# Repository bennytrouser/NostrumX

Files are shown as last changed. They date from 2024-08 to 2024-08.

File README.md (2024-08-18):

# NostrumX
A 32 key ergonomic split keyboard using Seeed Xiao BLE

This keyboard is a variation on my original [Nostrum](https://github.com/bennytrouser/nostrum) using a Seeeduino Xiao BLE with the battery mounted under the PCB within the case. Not designed to be used without the case.

The aim was to create a case based board while maintaining as much of the original shape and clean lines of the original nostrum pcb. 

- 3° Splay on pinky and ring columns
- Choc V1 switch compatible (hotswap or soldered). Hotswap recomennded as the switch plate is integrated into the case.
- Custom mildly tented case including switch sliders.
- MCU not socketed, SMD soldered only.
- Created with the [ergogen](https://github.com/ergogen/ergogen) and KiCad8. Case files created with Autodesk Fusion360.
- Firmware using ZMK, including the RGB Widget module from [Caksoylar](https://github.com/caksoylar/zmk-rgbled-widget)
- Inspiration from the [Hummingbird](https://github.com/PJE66/hummingbird) style [Berylline](https://github.com/jcmkk3/trochilidae#berylline) by [jcmkk3](https://github.com/jcmkk3)
- Mousebite breakaway tabs design are inspired by Sadekbaroudi's [bykeeb](https://github.com/sadekbaroudi/bykeeb)

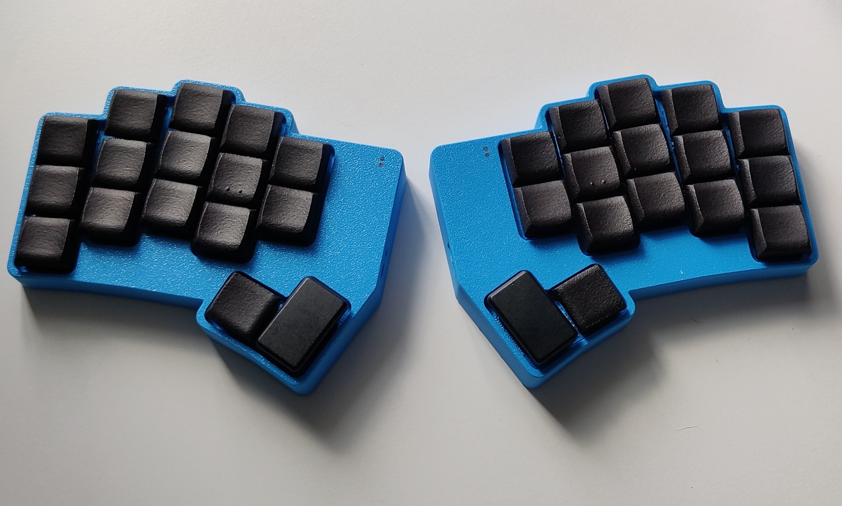
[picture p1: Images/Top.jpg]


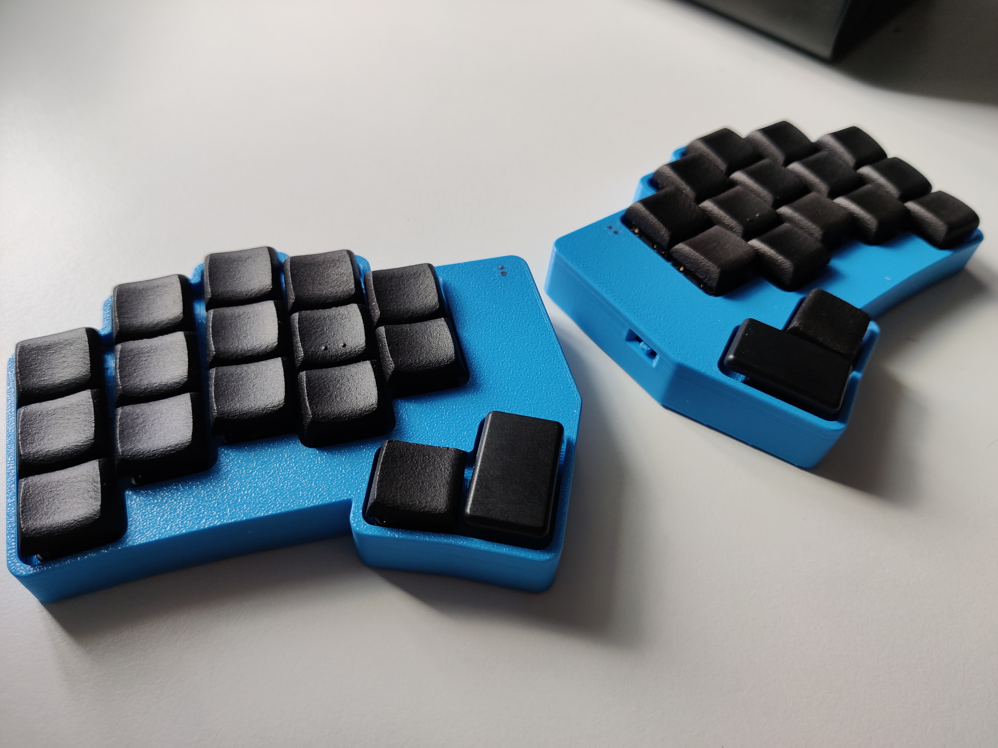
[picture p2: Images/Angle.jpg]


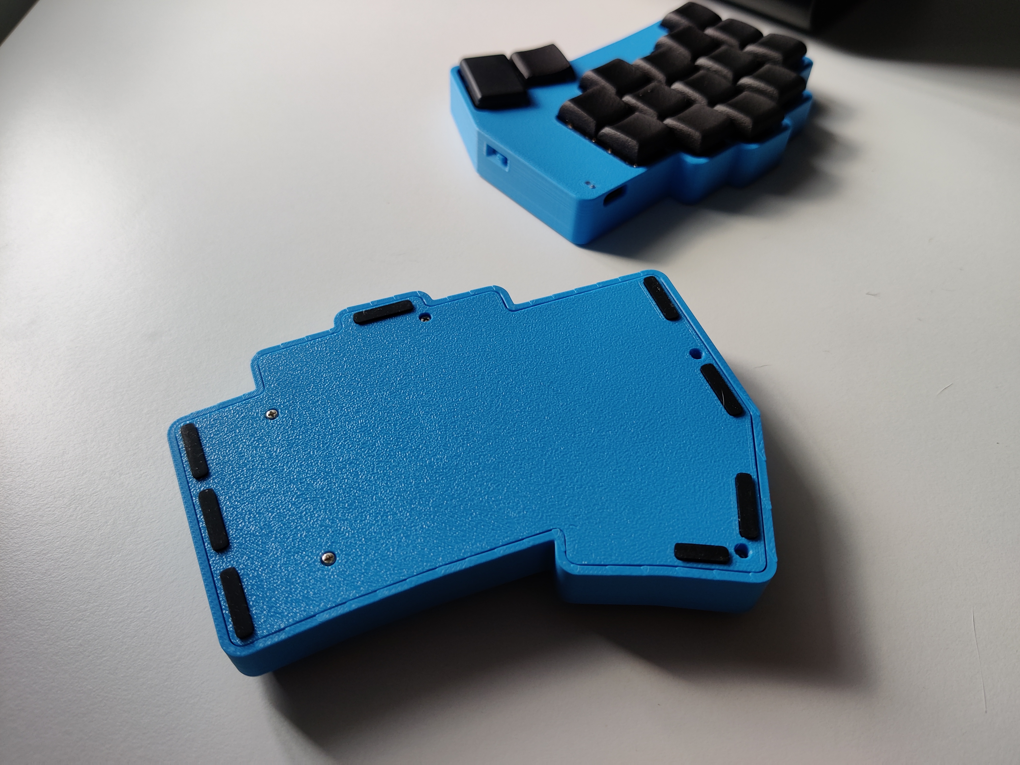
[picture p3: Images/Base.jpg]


## PCB
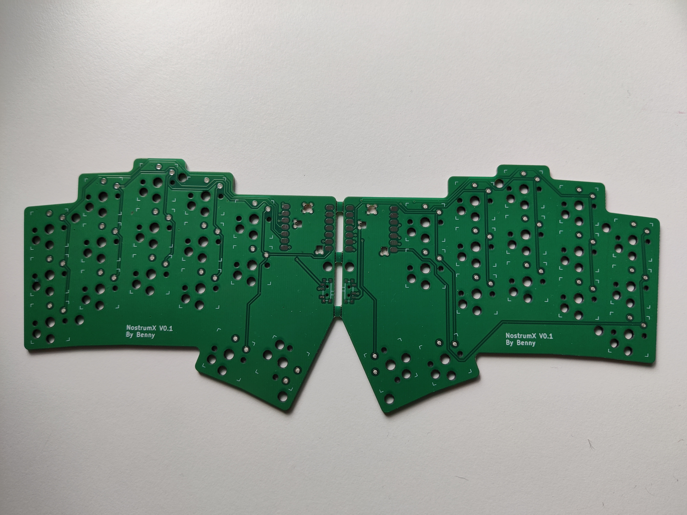
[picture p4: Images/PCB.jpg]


## Parts
The case is designed to be fastened from the underside using M1.5x6mm self tapping screws. Feet used are 10x3x1.5mm and 14x3x1.5mm. Left side has space to fit a lipo Battery 402030(180mah). Due to constraints, the right side will need a narrower battery if using hotswap. For my build, I used a 401322 (120mah) but a different size may fit. Example parts listed below. Source your switches and sockets and MCUs where available.

| Part  | Link |
| --- | --- |
| Battery 402030 | https://www.ebay.co.uk/itm/355875616696 |
| Battery 401322 | https://www.ebay.co.uk/itm/195234785175 |
| Self tapping Screws M1.5x6mm | https://www.aliexpress.com/item/1005005469153402.html |
| SMD diodes SOD-123 1N4148W T4 | https://www.aliexpress.com/item/32948518338.html |
| 1.5mm Fibreoptic cable (for led shinethrough) | https://www.aliexpress.com/item/1005005886250822.html |
| Reset button TL3342 | https://www.aliexpress.com/item/1005007506687094.html |
| Power switch PCM12 | https://www.aliexpress.com/item/32912838968.html |
| Feet | https://www.aliexpress.com/item/1005006691343859.html |

## Case files
Designed in Fusion360. 3d printed. Recommended to print the top case with face down for texured finish. There are two different bottoms, with or without a hole for a reset switch depending on if you want to use one.

The Switch bits need to be fitted before installing the pcb and are a tight fit. Also may require a bit of jiggling to get the slider to seat correctly on install.

The holes on the top of the case allow the charge led and the user led to shine through. I have used fibre optic cable in these holes but it is optional and a tight fit that may require slight enlargement with a screwdriver or small drillbit for the cable to slide in. Any larger in the file and it's a little loose.

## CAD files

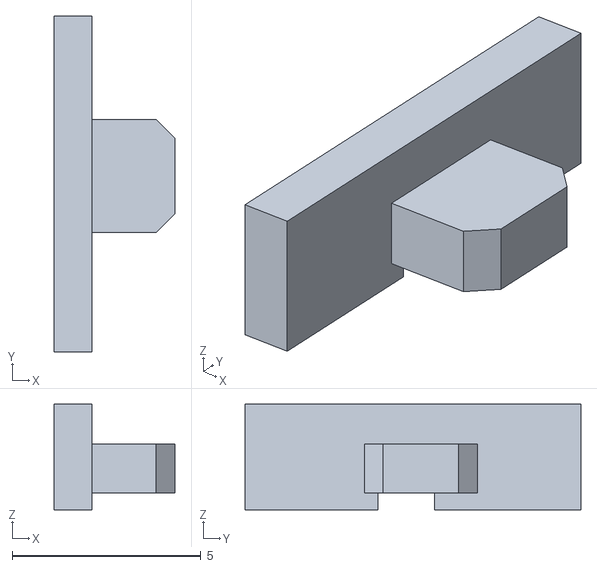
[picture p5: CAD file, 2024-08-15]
Case STLs/Switch bit Left.stl
3.20 x 8.90 x 2.80

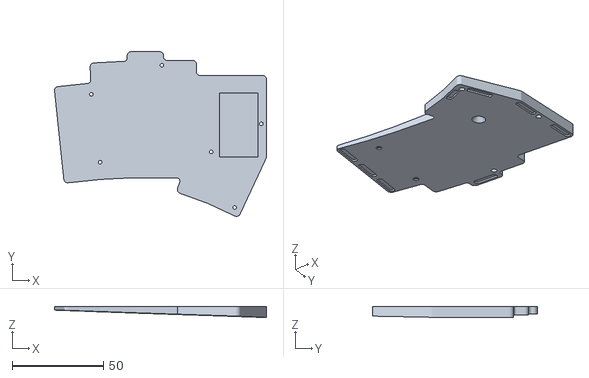
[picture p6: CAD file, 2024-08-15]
Case STLs/Left Bottom Case with reset.stl
115.9 x 90.1 x 6.12

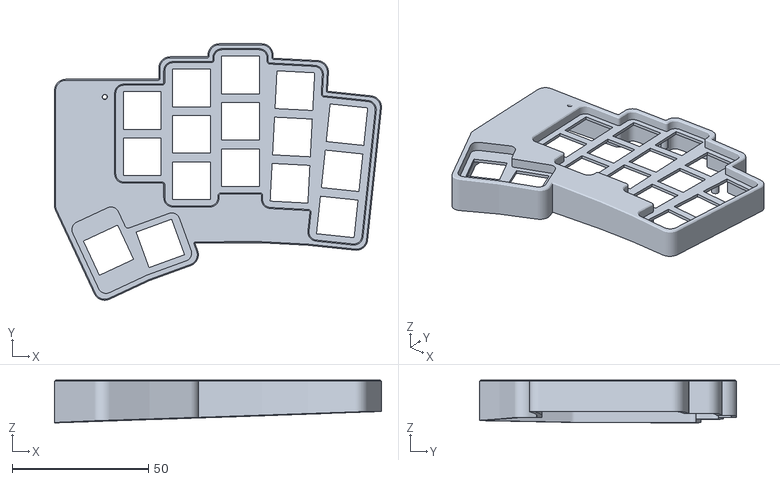
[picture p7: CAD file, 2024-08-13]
Case STLs/Right Top.stl
119.9 x 94.1 x 15.7

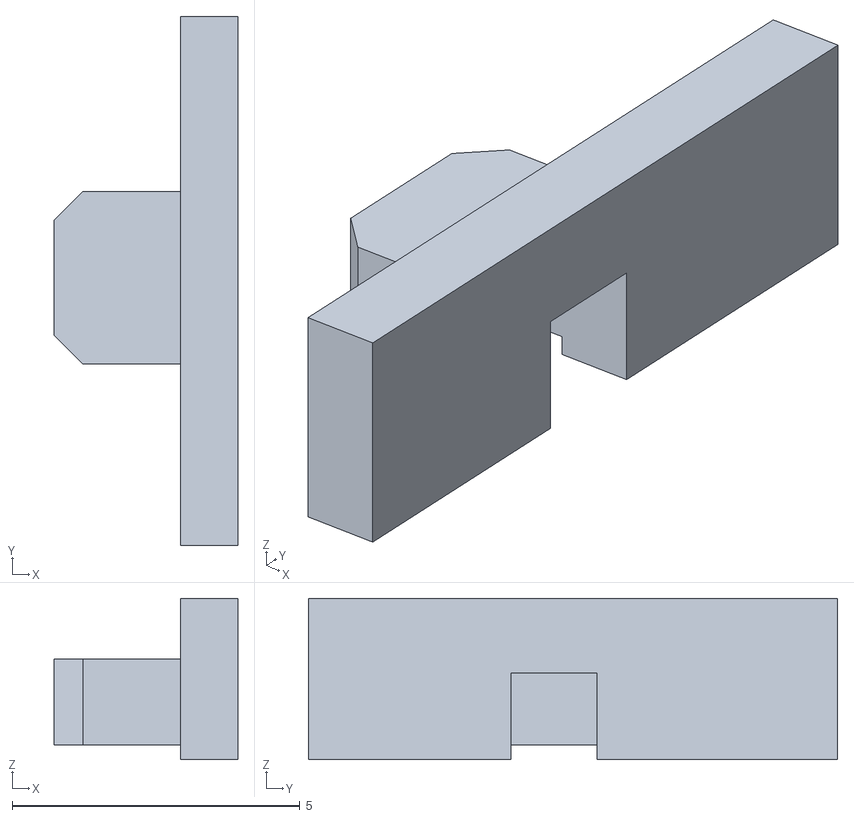
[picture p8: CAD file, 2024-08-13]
Case STLs/Switch bit Right.stl
3.20 x 9.20 x 2.80

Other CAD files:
Case STLs/Right Bottom Case with reset.stl
Case STLs/Right Bottom no reset hole.stl
Case STLs/Left Bottom no reset hole.stl
Case STLs/Left Top.stl

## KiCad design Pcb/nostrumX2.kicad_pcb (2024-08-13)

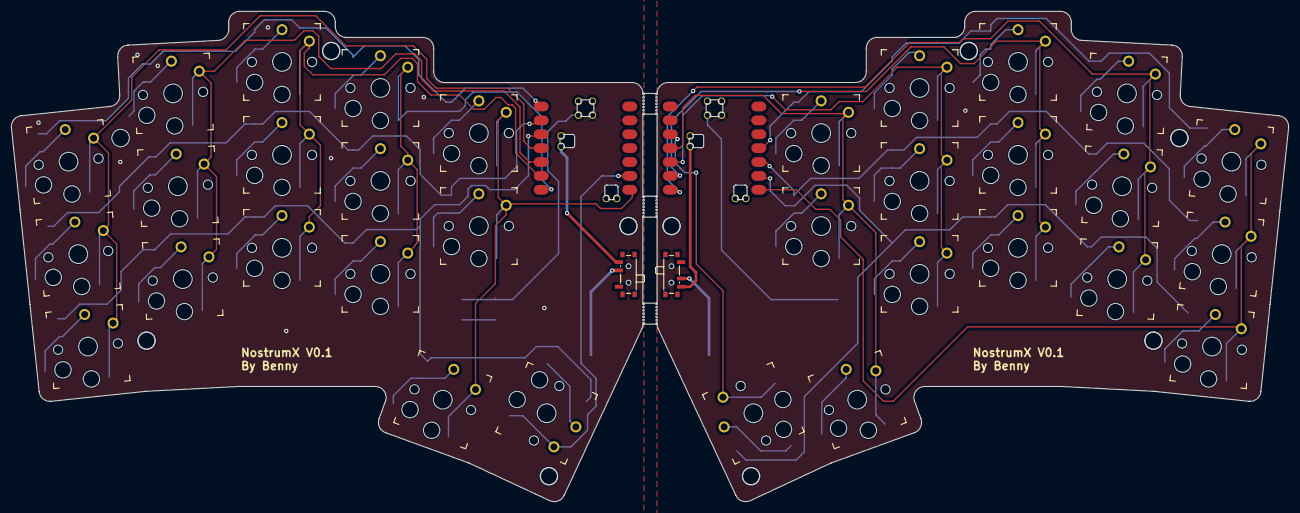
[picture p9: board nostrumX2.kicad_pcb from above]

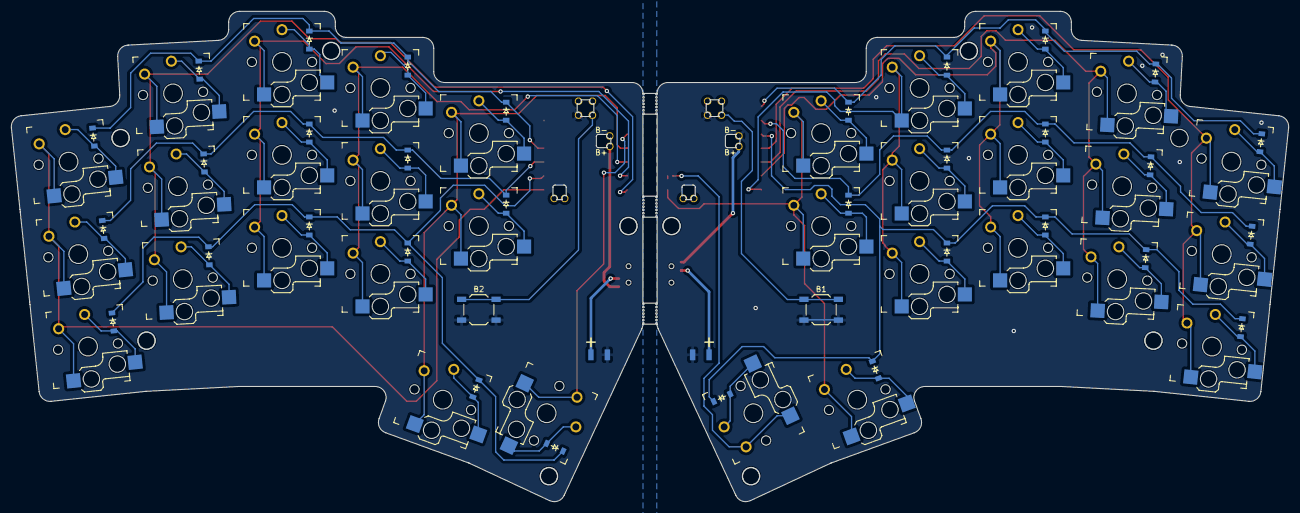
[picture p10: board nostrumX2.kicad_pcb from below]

Board: 2 copper layers, 233.6 x 89.7 mm, 79 parts (34 on the bottom side), 52 nets.

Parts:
B1, B2: SW_SPST_TL3342
D1, D2, D3, D4, D5, D6, D7, D8, D9, D10, D11, D12, D13, D14, D15, D16, D17, D18, D19, D20, D21, D22, D23, D24, D25, D26, D27, D28, D29, D30, D31, D32: ComboDiode
LH1, LH2, LH3: Breakaway Tabs; Breakaway_Tabs_Med
Mount: MountingHole_3.2mm_M3
PAD1, PAD2, PAD3, PAD4: SMDPad
RH1, RH2, RH3: Breakaway Tabs; Breakaway_Tabs_Med
S1, S2, S3, S4, S5, S6, S7, S8, S9, S10, S11, S12, S13, S14, S15, S16, S17, S18, S19, S20, S21, S22, S23, S24, S25, S26, S27, S28, S29, S30, S31, S32: PG1350
SW1, SW2: SW_SPDT_PCM12

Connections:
C0: S1.1, S2.1, S3.1
C1: S4.1, S5.1, S6.1
C2: S7.1, S8.1, S9.1
C3: S10.1, S11.1, S12.1
C4: S13.1, S14.1, S29.1
GND: B1.2, PAD2.1
MC0: S15.1, S16.1, S17.1
MC1: S18.1, S19.1, S20.1
MC2: S21.1, S22.1, S23.1
MC3: S24.1, S25.1, S26.1
MC4: S27.1, S28.1, S31.1
MGND: B2.2, PAD4.1
MR0: D19.1, D22.1, D25.1, D28.1, D30.1
MR1: D18.1, D21.1, D24.1, D27.1, D29.1
MR2: D17.1, D20.1, D23.1, D26.1, D31.1, D32.1
Mpos: PAD3.1, SW2.2
R0: D3.1, D6.1, D9.1, D12.1, D14.1
R1: D2.1, D5.1, D8.1, D11.1, D13.1
R2: D1.1, D4.1, D7.1, D10.1, D15.1, D16.1
index_bottom: D10.2, S10.2
index_home: D11.2, S11.2
index_top: D12.2, S12.2
inner_bottom: D13.2, S13.2
inner_home: D14.2, S14.2
left_home: D15.2, S29.2
middle_bottom: D7.2, S7.2
middle_home: D8.2, S8.2
middle_top: D9.2, S9.2
mirror_index_bottom: D26.2, S24.2
mirror_index_home: D27.2, S25.2
mirror_index_top: D28.2, S26.2
mirror_inner_bottom: D29.2, S27.2
mirror_inner_home: D30.2, S28.2
mirror_left_home: D31.2, S31.2
mirror_middle_bottom: D23.2, S21.2
mirror_middle_home: D24.2, S22.2
mirror_middle_top: D25.2, S23.2
mirror_pinky_bottom: D17.2, S15.2
mirror_pinky_home: D18.2, S16.2
mirror_pinky_top: D19.2, S17.2
mirror_right_home: D32.2, S32.2
mirror_ring_bottom: D20.2, S18.2
mirror_ring_home: D21.2, S19.2
mirror_ring_top: D22.2, S20.2
pinky_bottom: D1.2, S1.2
pinky_home: D2.2, S2.2
pinky_top: D3.2, S3.2
pos: PAD1.1, SW1.2
right_home: D16.2, S30.2
ring_bottom: D4.2, S4.2
ring_home: D5.2, S5.2
ring_top: D6.2, S6.2

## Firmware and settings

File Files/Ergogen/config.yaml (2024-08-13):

units:
  capx: 17.5   # Actual mbk size
  capy: 16.5   # Actual mbk size
  thumbcapx: 26.5 # Actual mbk 1.5u length
  kx: cx + 0.5    # Key spacing horizontal
  ky: cy + 0.5    # Key spacing vertical
  pinky_splay: 3  # Degrees of splay between pinky and ring columns
  pinky_adj: -10   # Adjustment to compensate for splay spacing
  ring_splay: 3
  ring_adj: -8
  middle_splay: 0
  middle_adj: 0
  thumb_offsetx: 0.25kx
  xiao_x: 17.5
  xiao_y: 21
  outx: 0.5capx +1  # Used for plate outlines
  outy: 0.5capy +1  # Used for plate outlines
  mirshift: 31

points:
  # Key Zones
  zones:
  zones.matrix:
    anchor:
      shift: [100,-100]
      rotate: ring_splay + pinky_splay
    mirror:
      ref: matrix_inner_home
      shift: mirshift
    key:
      width: capx
      height: capy
      spread: cx      
      padding: cy
    rows:
      bottom:
        row_net: R2
        mirror.row_net: MR2
        bind: [1, 1, 1, 1]
      home:
        row_net: R1
        mirror.row_net: MR1
        bind: [1, 1.5, 0, 1]
      top:
        row_net: R0
        mirror.row_net: MR0
        bind: [1, 2, 0, 1]
    columns:
      pinky:
        key:
          column_net: C0
          mirror.column_net: MC0
          rows:
            bottom:
              bind: [1, 1, 1, 1]
            home:
              bind: [1, 1.5, 0, 1]
            top:
              bind: [1, 2, 0, 1]
      ring:
        key:
          column_net: C1
          mirror.column_net: MC1
          stagger: 0.55U
          splay: -pinky_splay
          origin: [0, pinky_adj]
        rows:
          bottom:
            bind: [1,1.5,11.9,0]
          home:
            bind: [1,1.5,0,1]
          top.:
            ind: [1,2,1,1]
      middle:
        key:
          column_net: C2
          mirror.column_net: MC2
          stagger: 0.25U
          splay: -ring_splay
          origin: [0, ring_adj]
        rows:
          bottom:
            bind: [1,1,17.1,0]
          home:
            bind: [1,1,0,1]
          top:
            bind: [1,1,0,1]
      index:
        key:
          column_net: C3
          mirror.column_net: MC3
          stagger: -0.25U
        rows:
          bottom:
            bind: [1,1,12.341,1]
          home:
            bind: [1,1,0,1]
          top:
            bind: [1,1,0,1]
      inner:
        key:
          column_net: C4
          mirror.column_net: MC4
          stagger: 0.5ky
        rows:
          top.skip: true
          bottom:
            row_net: R1
            mirror.row_net: MR1
            bind: [1,2,22.590471307,1]
          home:
            row_net: R0
            mirror.row_net: MR0
            bind: [1,2,20,1]
  zones.thumb:
    anchor:
      ref: matrix_index_top
      shift: [0.6u,-57]
      rotate: -20
    mirror:
      ref: matrix_inner_home
      shift: mirshift
    key:
      width: capx
      height: capy
    rows:
      home:
        row_net: R2
        mirror.row_net: MR2
    columns:
      left.key:
        name: thumb_tucky
        bind: [0,3,1,1] # U,R,D,L
        column_net: C4
        mirror.column_net: MC4
      right.key:
        spread: kx+0.2
        stagger: 0.225kx
        rotate: -95
        name: thumb_reachy
        bind: [1,1,2,1.2191] # R,D,L,U
        column_net: C5
        mirror.column_net: MC5

  # Components Zones

  # MCU
  zones.mcu:
    anchor:
      ref: matrix_inner_home
      shift: [19.5,-2.75]
      rotate: 0
    mirror: 
      ref: matrix_inner_home
      shift: mirshift
    key:
      name: mcu
      width: xiao_x+1
      height: xiao_y+1

  # Power slider
  zones.pcm12:
    anchor:
      - ref: mcu
        shift: [0.5xiao_x+0.3, -1.1xiao_y]
        rotate: 0
    key:
      name: pcm12
      height: 6.7
      width: 2.6
    mirror:
      ref: matrix_inner_home
      shift: mirshift

  # Reset switch
  zones.reset:
    anchor:
      - ref: matrix_inner_bottom
        shift: [0, -0.9cy]
    key:
      name: reset
      height: 3
      width: 2.5
    mirror:
      ref: matrix_inner_home
      shift: mirshift
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

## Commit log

2024-08-13 Updated files and readme
    [Left Bottom no reset hole.stl, Left Top.stl, Right Bottom no reset hole.stl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]
2024-08-15 Final update
    [Left Bottom Case with reset.stl, Right Bottom Case with reset.stl, Switch bit Left.stl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]
